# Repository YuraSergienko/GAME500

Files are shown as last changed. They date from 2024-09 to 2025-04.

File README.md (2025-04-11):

# GAME500

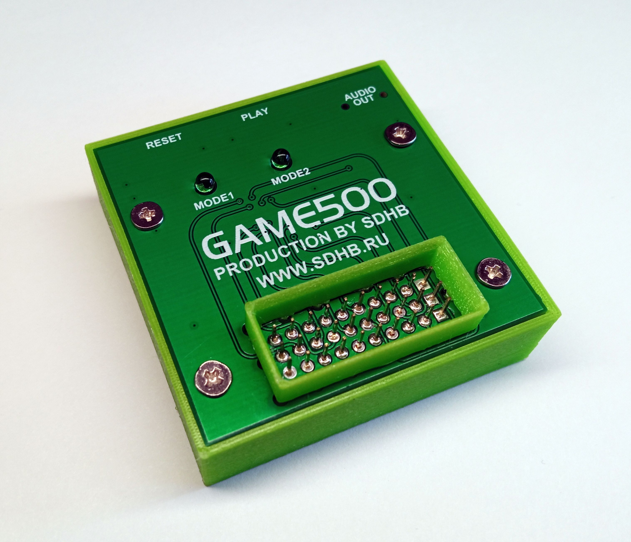
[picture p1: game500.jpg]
GAME500


<b>ROM картридж для компьютера "Вектор-06Ц"</b>

GAME500 - простое устройство для быстрой загрузки любимых программ. Для подключения к "Вектору" использется порт ПУ, а также при необходимости
магнитофонный вход. GAME500 эмулирует ROM картридж поддержка которого есть в большенстве загрузочных ПЗУ. Если же в "Векторе" установлено
заводское загрузочное ПЗУ без поддержки ROM картриджа, на GAME500 есть аудиовыход, который нужно подключить к магнитофонному входу "Вектора".
При нажатии кнопки "PLAY" на GAME500, с него воспроизводится небольшая программа-загрузчик с поддержкой ROM картриджей.

Содержание папок репозитория:<br>
asm - исходные коды для загрузчиков и файловой оболочки.<br>
box - stl модели корпусных деталей картриджа.<br>
doc - документация на изделие.<br>
flash - программа и файлы для подготовки bin файла для записи в микросхему флэш памяти W25Q128.<br>
gerber - GERBER файлы для производства печатной платы.<br>
src - проект в среде MounRiver для микроконтроллера CH32V103C8T6.<br>
src/obj/game500.hex - файл прошивки микроконтроллера CH32V103C8T6.<br>

<b>ROM cartridge for the Vector-06C computer</b>

GAME500 is a simple device for quickly loading your favorite programs. The "ПУ" port is used to connect to the "Vector", and if necessary,
the tape recorder input. GAME500 emulates a ROM cartridge, which is supported by most boot ROMs. If the "Vector" has a factory boot ROM
without support for a ROM cartridge, the GAME500 has an audio output that needs to be connected to the tape recorder input of the "Vector".
When you press the "PLAY" button on the GAME500, a small bootloader program with support for ROM cartridges is played from it.

Contents of repository folders:<br>
asm - source codes for loaders and file manager.<br>
box - stl models of cartridge body parts.<br>
doc - product documentation.<br>
flash - program and files for preparing a bin file for recording in the W25Q128 flash memory chip.<br>
gerber - GERBER files for PCB production.<br>
src - project in the MounRiver IDE for the CH32V103C8T6 microcontroller.<br>
src/obj/game500.hex - firmware file for the CH32V103C8T6 microcontroller.<br>

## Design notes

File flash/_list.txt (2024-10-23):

_game500.rom File manager
fdcosmos.rom ACongueteCosmos
afterwar.rom After The War
agress1.r0m Agressor
airfight.rom Air Fighter
AIDSJUN.ROM Aids! Jun
AIDSMID.ROM Aids! Mid
airforcs.rom Air Force
alfred.rom Alfred
alibaba.rom Alibaba&40Thiev
alambush.rom Alien Ambush
apdig.rom Ap-Digger
APEX.ROM Apex
arkanoid.rom Arkanoid
arkan4.rom Arkanoid mod
asteroids.rom Asteroids
assaut.rom Assaut
park.rom Athletic Land
bacbyl.rom Back
barman.rom Barman
Batle_Tank.rom Battle Tank
karate.rom BestOfTheBest
best.rom BestOfTheBest+
billy.rom Billy
binland.rom Binary Land
Binorum.rom Binorum
blackjack_cas.rom BlackJack
blaster.rom Blaster
bomber.rom Bomber
jungle_jps.rom Boogie Woogie J
BORDHOLL.ROM Border-Hollow
bouldush.rom Boulder Dash
boulderd.rom Boulder Dash2.0
bouldd11.rom Boulder Dash1.1
bouldd22.rom Boulder Dash2.2
house.rom Break House
BUSINESS.ROM Business
caeon.rom Caeon
cball.rom Cannon Ball
ceilon.rom Ceilon
chaser.rom Chaser
chasse.rom Chasse
chesse.rom Cheese
cheese2.rom Cheese2
SHAHM2.ROM Chess-2
chesmast2.rom Chess Master
CHESMAST.ROM Chessmaster
chipdale.rom Chip&Dale(alfa)
chronos.rom Chronos
colball.rom Color Ball
clrball_new.rom Color Ball New
collines.rom Color Lines
columns.rom Columns
columns2.rom Columns 2
columns3.rom Columns IBM
cookie.rom Cookie
cooky2.rom Cooky-2
cosman.rom Cosman
crapaut.rom Crapaut
crazy.rom Crazy Train
cronex.rom Cronex
CYBERMUT.ROM Cyber Mutant
cybernbr.rom Cybernoid
dangerick.rom Dangerous Rick
DATEAU.ROM Dateau
DFIGHT.ROM Death Fight
deathstr.rom Death Star
pyr-df99.rom DeathInPyramid
desolate.rom Desolate
dcountry.rom Diamond Country
dcountr2.rom DiamondCountry2
dino1.rom Dino
DIZZY-S.ROM Dizzy
donkong.rom Donkey Kong
DOWN.ROM Down To Earth
DEAR-BST.ROM DownToEarth BST
DEAR-RS.ROM DownToEarth RS
DEAR-RSY.ROM DownToEarth RSY
DOWN1.ROM Down To Earth
driller.rom Driller Tanks
airman.rom Duble Airman
dungeon.rom Dungeon
eaglesn.rom Eagle Snest
earth3.rom Earth Shaker
efa.rom Efa
ERASER.ROM Eraser
eric.rom Eric & Floaters
exolon.rom Exolon
ExolonM2.rom Exolon M2
fantom.rom Fantom
fantom2.rom Fantom2
FATAX.ROM Fatax
FATAXCOL.ROM Fatax Color
features.rom Features
filer.rom Filer
fire.rom Fire Rescue
flight.rom Flight
flyspirt.rom Flying Spirit
football.rom Footbal
forpostm.rom Forpost
fortuna.rom Fortuna
frogger.rom Frogger
fuite.rom Fuite
galaxan.rom Galaxan
ghostbus.rom Ghostbusters
global.rom Global Rally
hairwarr.rom Hair Warrior
harrier.rom Harrier
helicopt.rom Helicopter
indian.rom IndianNoBouken
intercep.rom Intercepter
karatet.rom Int. Karate T
jetset.rom Jet Set Willy
joeblade.rom Joe Blade
jumpjack.rom Jump-Jek
konfetti.rom Konfetti
LABIRINT.ROM Labirynt
LAND.ROM Land
landing.rom Landing
lapi.rom Lapi
liberator.rom Liberator
LODERUN.ROM Lode Runner
loderun2.rom Lode Runner2
LOGIC.ROM Logic
LIFE.ROM Life
macsit.rom Macsit
magpap1.r0m Magic Paper
mars.rom Mars
MAZE.ROM Maze
micmouse.rom Mickey Mous
NICKCHES.ROM Mikes Chess
mines.rom Mines
mineswep.rom Mine Sweeper
monstre.rom Monstre
moonbase.rom Moonbase
moonbugs.rom Moon Bugs
mower.rom Mower
TARZAN.ROM New Tarzan
niagar.rom Niagara Falls
ninja.rom Ninja Kage
ohmummy.rom Oh, Mummy
osciller.rom Osciller
outrun.rom Outrun
pacman.rom Pac-Man
PACMNCLR.ROM Pac-Man Color
pairs.rom Pairs
pdizzy.rom Panic Dizzy
PARITY.ROM Parity
pif-paf.rom Pif-Paf
pillars.rom Pillars
pipedr.rom Pipe Dream
pitongln.rom Piton GLN
polygame.rom Polygame
pool.rom Pool
preda1im.rom Predator 1
predato2.rom Predator 2
psst.rom Psst
pusher.rom Pusher
push.rom Push
putup.rom Putup
raider.rom Raider
RAIDER2.ROM Raider2
ranger.rom Ranger
REVSEX1.ROM Reverse Sex1
REVSEX2.ROM Reverse Sex2
REVERSI.ROM Reversi
riseout.rom Riseout
ROBBO1.ROM Robbo
ROBBO2.ROM Robbo-II
ROBBO3.ROM Robbo-III
robotek.rom Roboteka
rockman.rom Rock Man
rockman2.rom Rock Man2
rockman16.rom Rock Man16
rockford.rom Rockford
rotors.rom Rotors
runner.rom Runner
runer_ok.rom Runner OK
SABOTEUR.ROM Saboteour
salesman.rom Salesman
seggs.rom Scramble Eggs
sherly.rom Sherly
shoptour.rom Shop Tour
sidearm.rom Side Arm
snake.rom Snake
snake2.rom Snake2
sland.rom Snare Land
SOBDOG.ROM Sobdog
spcdemon.rom Space Demon
SPMEGAIM.ROM Space Megatron
spacop.rom Spacor
sdemise.rom Spy's Demise
stalker.rom Stalker
STARWARS.ROM Star Wars
starfighter.rom Starfighter
stars.rom Stars
stars2.rom Stars II
stepjump.rom Step And Jump
STINGER2.ROM Stinger 2
stonkers.rom Stonkers
iexpress.rom Stop Express
sgibbon.rom Super Gibbon
maric.rom Super Maric
superwea.rom Super Weapon
tankbat.rom Tank Battalion
tankwars.rom Tank Wars
terminus.rom Terminus
tetrisk.rom Tetris K
RUNERMAN.ROM The Ranner Man
tower.rom Tower
TRANSMUT.ROM Trans Muter
TRIP.ROM Trip
tron.rom Tron
TUTANKH2.ROM Tutankhamun
upriver.rom Up The River
w1.rom W-1
WAMPIRL.ROM Wampir Land
warp.rom Warp, Warp
westbank.rom West Bank
whouse.rom Wonder House
xorz.rom Xorz
xonix.rom Xonix
XONIXS.ROM Xonix S
xonixsn.rom Xonix SN
xonix_copy.rom Xonix OK
xyzolog.rom Xyzolog
zodiac.rom Zodiak
sokoban.rom Zoko-Ban
xzone.rom Zone X
ZORYT.ROM Zoryt
ochko101.rom 101 Очко
semvinej.rom 7 Виней
abrams.rom Абрамс
ADSKOK.ROM Адскок
akula.rom Акула
ambal.rom Амбал
ambalm.rom Амбал-М
arktika.rom Арктика
arktika_.rom Арктика2
armiya8.rom Армия 8
ATNINJA.ROM Атака Ниндзя
BILLIARD.ROM Биллиард
boldercr.rom Болдер
bolder2.rom Болдер 2
bolderm.rom Болдер-М
bolderpp.rom Болдер++
bombard.rom Бомбардировщик
BRONEVIK.ROM Броневик
burya.rom Буря в пустыне
vertolet.rom Вертолёт
vodolaz.rom Водолаз
vozdshar.rom Воздушный Шар
voleybol.rom Волейбол
vorishka.rom Воришка
gpatrul.rom Гала Патруль
gomoku.rom Го-Моку
golkiper.rom Голкипер
grotohod.rom Гротоход
dengolos.rom Деньголов
digger.rom Диггер
dizzi.rom Диззи
doroga.rom Дорога
irworld.rom Железный мир
LIFE2.ROM Жизнь
zamok.rom Замок
spacewar.rom Звездные Войны
sranger.rom Звездный Ренжер
ZPLANETA.ROM Зеленая Планета
ZONA.ROM Зона Будущего
CRITTERS.ROM Зубастики
istrebit.rom Истребитель
jeti.rom Йети
jeti2.rom Йети 2
karti.rom Карты
karateka.rom Каратека
karatek.rom Каратэ
kvadrati.rom Квадраты
kirash.rom Кираш
KIJANKA.ROM Киянка
KIJANKA2.ROM Киянка 2
KLAD.ROM Клад
klad2.rom Клад2
KLETKA.ROM Клетка
kobra.rom Кобра
KOLOBEG.ROM Колобег
KOLOPUNC.ROM Колобок
kolobiha.rom Колобиха
commandz.rom Коммандер
kotprigun.rom Кот-прыгун
kotribolov_copy.rom Кот-рыболов
kresnull.rom Крестики-Нолики
labir1.rom Лабиринт-1
lender.rom Лэндер
lendern.rom Лэндер-Н
MAGSHAR.ROM Магический Шар
mirsm.rom Мир Смерти
mohotnik.rom Морской Охотник
mohotni2.rom МорскойОхотник2
NARDI.ROM Нарды
nashchha.rom Нашествие
nupogodi.rom Ну, Погоди
ochko.rom Очко
ohota.rom Охота
parashut.rom Парашютисты
pasjansi.rom Пасьянсы
pakmanen.rom Пекманёнок
pecshera.rom Пещера
PESCHER1.ROM Пещера 2
pesprizr.rom Пещера Призраков
PITON.ROM Питон Успид
pitong.rom Питон
PLANETA.ROM Планета Птиц
plyuk.rom Плюк
poddavki.rom Поддавки
poker.rom Покер
polet.rom Полёт
popcorn.rom Попкорн
poprigun.rom Попрыгунчик
posad06c.rom Посадка
POHIWANA.ROM ПохожденияИвана
PREZID.ROM Президент
PRUZASOV.ROM ПрограммаУжасов
plifter.rom Пьяный Лифтёр
incurzion.rom Рива Рейд
SHASHKI.ROM Русские Шашки
rembo.rom Рэмбо
sabotaz.rom Саботаж
samuray.rom Самурай
spacesaf.rom СафариЗаВампирм
SEKA.ROM Сека
slalom.rom Слалом
sokoban_copy.rom Сокобан
sokzamka.rom Сокровища Замка
faraon.rom СокровищФараона
spichki.rom Спички
spsmerti.rom Спутник Смерти
spgroup1.rom Спецгруппа
sragen1.rom Сражение
sragen2.rom Сражение 2
srazsnlo.rom Сражение с НЛО
ot.rom Старая Башня
SUPKALAH.ROM Супер Калах
TANK.ROM Танк 
tennis_copy.rom Теннис
tetris.rom Тетрис
tetrisii.rom Тетрис II
tetriso.rom Тетрис-О
tetrisok.rom Тетрис-ОК
tetrisp.rom Тетрис-П
tir.rom Тир
trutni.rom Трутни
turboudav.rom Турбоудав
UGOLKI.ROM Уголки
uzas1.rom Ужас 1
uzas2.rom Ужас 2
UZAS3.ROM Ужас 3
flyer.rom Флаер
formula1.rom Формула 1
himiya.rom Химия
cvkvadr.rom Цветные квадрат
circus.rom Цирк
chsund1.rom Чудо Сундук1
chsund2.rom Чудо Сундук2
chsund3.rom Чудо Сундук3
sharik.rom Шарик
KLASSHES.ROM Шахматы
SHAHM1A.ROM Шахматы 1.1
SHAHM4.ROM Шахматы
shturm.rom Штурм
animator21.rom Аниматор
dekorator11.rom Декоратор
karandas.rom Карандаш
REMBRANT.ROM Рембранд
MICROGR.ROM Micrograf
coman.rom Гр.ред. Coman
masced.rom Гр.ред. Masc Ed
M_UZOR.ROM Редактор узоров
spraite.rom РедакторСпр-тов
spted.rom Sprite Editor
CHAR.ROM Ред.знакогенер.
ekran.rom Экран
organ1.rom Organ
mad.rom Mad MusicEditor
golos.rom Голос
horus.rom Horus
cmu.rom Цветомузыка
ColorOfMusic.rom Color of Music
cwmdelta.rom Цветомуз. Delta
lmusic1.rom LightMusic
lmusic2.rom LightMusic2
CVM1.ROM Цветомузыка CVM1
CVM2.ROM Цветомузыка CVM2
notebook.rom Записная Книжка
RETEX.ROM Retex Editor
TEXTAS.ROM Texstas
KTV.ROM Редактор текста
profy1.rom Тренажёр Профи 
bd.rom БД Эрис
sip.rom Система Поиска
elkubiki.rom Электр. Кубики
autocw.rom Auto CW
CW.ROM Терминалка
pdt-112.rom Психол. Тест
BIORITMY.ROM Биоритмы
bioritm.rom Биоритмы2
sexschol.rom Школа Секса
SEXOR.ROM Sexor
bas261.rom Basic 2.61
bas262.rom Basic 2.62
basicm.rom Basic M
baskor.rom Basic Корвет
basicsig.rom Basic ПО Сигнал
reklama.r0m BAS Реклама
INFOR-1.r0m BAS Inform 1     
INFOR-2.r0m BAS Inform 2    
t_ataka.r0m BAS Торп. атака
kalah.r0m BAS Калах
space_station.r0m BAS Space Stat.
corpse.r0m BAS Corpse
vitamino.r0m BAS Витамино     
forth-83.rom Forth-83
LSPAS-I.ROM ЛС-Паскаль инт.
LSPAS-K.ROM ЛС-Паскаль ком.
mon25c.rom Монитор 2.5
mon26.rom Монитор 2.6
mon28.rom Монитор 2.8
mon40.rom Монитор 4
smon35g.rom Супер Монитор3.5
smon40.rom Супер Монитор4
mon1200.rom Монитор 1200
monpribm.rom Монитор Pribor
monvz1.rom МониторВзломщик
MONHEDM.ROM Monitor High
rk86.rom Монитор РК-86
micro_rk.rom Микроша-РК86
testtp.rom Тест Техпрогона
testustr.rom Тест Устройств
brdtestx.rom Border Test
kdtest.rom Тест квазидиска
kdtest2.rom Тест квазидиск2
GRAYTEST.ROM Тест серого
ozu.rom Тест ОЗУ
ozuda0.rom Тест ОЗУ2
ozudtprl.rom Тест ОЗУ3
TESTAY.ROM Test AY
TESTELD.ROM Test RAM Дождь
testram.rom Test RAM
fastpalprog.rom Тест FastPalPrg
cpress3.rom Press3.3 copier
goody.rom КопировщикGoody
fttcopy.rom FTT Copy
copy-copy.rom Copy-Copy
turbo.rom Turbo Copy
archiv13.rom Архиватор
dilarh.rom Копир-Архватор
copypack.rom Копир-упаковщик
beverley.rom ВИ53 Демо
gtoc64.rom ДемоPhaser c64
object3d.rom Demo 3D Objects
rc38.rom 3D demo rc38
rc46.rom 3D demo rc46
chip.rom Chip
art.rom Демо Art
art1.rom Демо Art 1
art2.rom Демо Art 2
art3.rom Демо Art 3
art4.rom Демо Art 4
art5.rom Демо Art 5
art6.rom Демо Art 6
art7.rom Демо Art 7
ART2-01.rom Демо Art2 1
ART2-02.rom Демо Art2 2
ART2-03.rom Демо Art2 3
ART2-04.rom Демо Art2 4
ART2-05.rom Демо Art2 5
ART2-06.rom Демо Art2 6
ART2-07.rom Демо Art2 7
ART2-08.rom Демо Art2 8
ART2-09.rom Демо Art2 9
ART2-10.rom Демо Art2 10
bazis.rom Демо Базис
musworld.rom Демо Musworld
sabrina.rom Демо Sabrina
beatles.rom Демо Beatles
demon.rom Муз.демо Demon
fancy.rom Муз.демо Fancy
KRISTI.ROM Демо Kristi
amiga.rom Демо Amiga
accel2.rom Демо Accel2
f29.rom Демо F29
pgz.rom Демо ПГЗ
pmasha.rom Демо Maria
realdemo.rom Демо Realdemo
spiral.rom Демо Spiral
artsamar.rom Art Samara
lyra2-3.rom Демо Lyra2-3
message.rom MuzDemo
man.rom Демо Man
ollilisa.rom Демо Olli&Lissa
komar.rom Комар
byte2122.rom Байт 21, 22

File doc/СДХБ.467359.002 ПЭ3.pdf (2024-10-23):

Изм. Лист | № докум. | Подп. | Дата
| Разраб. | Сергиенко | | | GAME500 Перечень элементов | Лит. | Лист | Листов
Пров. | | | | A 1

Н.контр.
Утв.
www.sdhb.ru Инв. № подл. Подп. и дата Взам. инв. № Инв. № дубл. Подп. и дата Справ. № Перв. примен. СДХБ.467359.02 | Конденсаторы
C1-C4, GRM21BR71H104K | | 6
C7,C8
C5, C6 GRM2165C1H270JZ01D | | 2
C9 | GRM21BR61E106KA73L | 1
C10 | GRM2165C1H222JA01D | 1
C11 | GRM21BR71C105KA01K | 1
| Микросхемы
DA1 | LD1117AS33TR | 1
DD1 | CH32V103C8T6 | 1
DD2 | W25Q128JVSIQ | 1
| Резисторы
R1-R7, RC0805FR-0710KL | | 8
R11
R8, R9 RC0805FR-07510RL | | 2
R10 | RC0805FR-0724KL | 1
| Диоды
VD1, VD2 L-1154GT | | 2
| Разъемы
X1-X3 PLL1.27-20 | | 3
XS1 | PJ-W17-03 | 1
| Прочие элементы
SB1, SB2 Кнопка IT4-1102USA | | 2
ZQ1 | Кварц HC-49US, 8 МГц | 1
| | | СДХБ.467359.02 ПЭ3

Поз.
обозначение
Наименование | Кол. Примечание
Копировал | Формат A4

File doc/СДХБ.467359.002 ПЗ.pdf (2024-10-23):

Перв. примен. СДХБ.467359.002 Справ. № Подп. и дата Инв. № дубл. Взам. Инв. № Подп. и дата

| | | | СДХБ.467359.002 ПЗ
| Изм. Разраб. Лист | Сергиенко № докум. | Подп. | Дата Инв. № подл. | GAME500 Пояснительная записка | Лит. | Лист | Листов
Пров. | | | | А | | | 1 | 6
Н. контр. | www.sdhb.ru
Утв.
| Формат А4

## GAME500

## СДХБ.467359.002

## ПОЯСНИТЕЛЬНАЯ ЗАПИСКА

Подп. и дата Инв. № дубл. Взам. инв. № Подп. и дата Инв.№ подл. СДХБ.467359.002 ПЗ

Лист

Изм. | Лист | № докум. | Подп. | Дата

2

ВВЕДЕНИЕ

GAME500 - простое устройство для быстрой загрузки любимых программ. Для подключения к "Вектору" используется порт ПУ, а также при необходимости магнитофонный вход. GAME500 эмулирует ROM картридж поддержка которого есть в большинстве загрузочных ПЗУ. Если же в "Векторе" установлено заводское загрузочное ПЗУ без поддержки ROM картриджа, на GAME500 есть аудиовыход, который нужно подключить к магнитофонному разъему "Вектора". При нажатии кнопки "PLAY" на GAME500, с него воспроизводится небольшая программка-загрузчик с поддержкой ROM картриджей.

### 1. СБОРКА ПЕЧАТНОЙ ПЛАТЫ

### 1.1. СБОРКА РАЗЪЕМА

Так как разъемы СНП34-30В довольно дорого и сложно приобрести, в GAME500 используется его замена. Штырьки используются от PLS гребенки, а корпус печатается на 3D принтере.

Прежде чем начать сборку платы необходимо подготовить PLS гребенки. Для этого PLS гребенка с 20 контактами и с шагом 1.27 прореживается, через одну, чтобы получилась гребенка с 10 контактами и шагом 2.54. Далее гребенка вставляется в пустую печатную плату. Прижимая в плотную к плате пластиковой держатель штырьков добиваются максимальной длины контактов (Рис. 1).

Рисунок 1

Подп. и дата Инв. № дубл. Взам. инв. № Подп. и дата Инв.№ подл. СДХБ.467359.002 ПЗ

3

Необходимо изготовить три таких гребенки. После сборки платы они запаиваются в последнюю очередь, используя для выравнивания подходящий ответный разъем типа СНП34 или ПУ выход "Вектора". После запайки гребенок необходимо удалить пластиковые держатели и установить корпус-рамку разъема, которая фиксируется оплавлением с обратной стороны.

### 1.2. МОНТАЖ СВЕТОДИОДОВ

Светодиоды вставляются в соответствующие отверстия, контакты разгибаются и отрезаются так, чтобы они попадали на контактные площадки, после чего запаиваются.

При установке соблюдайте правильную полярность светодиодов.

### 1.3. МОНТАЖ КНОПОК

Перед монтажом кнопок необходимо отогнуть торчащий лепесток корпуса кнопки на 90 градусов (Рис. 2), после чего кнопка запаивается большим количеством припоя.

Рисунок 2

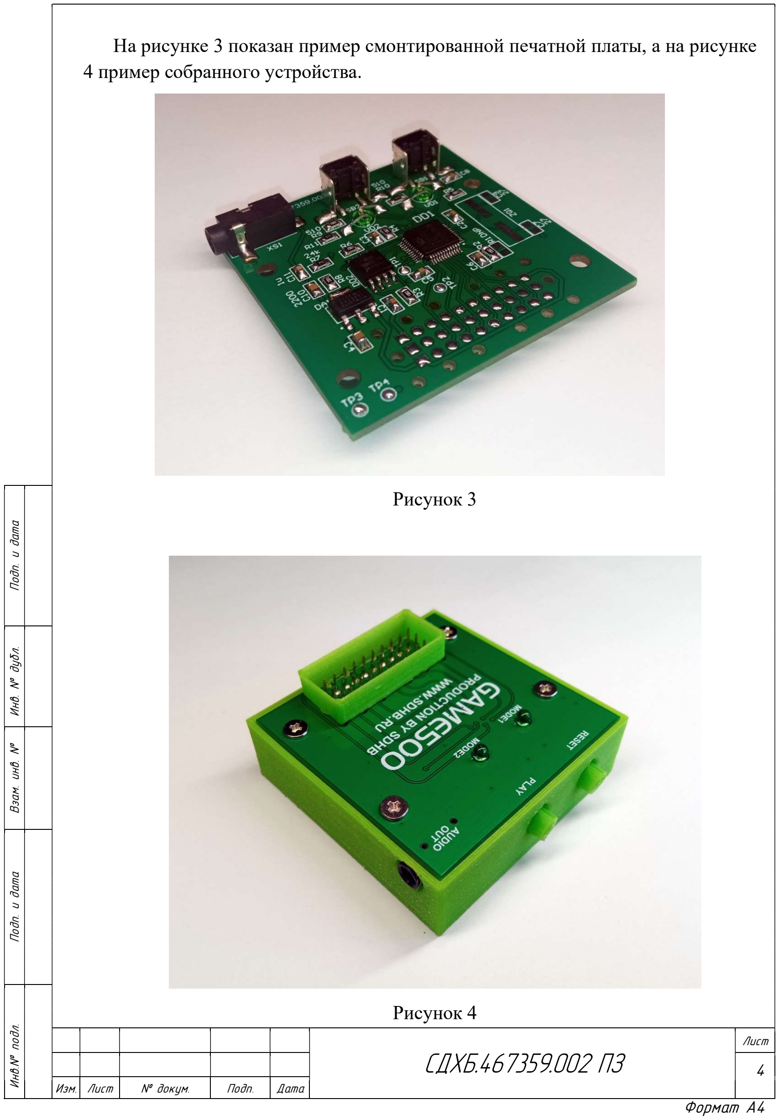
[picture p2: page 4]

Подп. и дата Инв. № дубл. Взам. инв. № Подп. и дата Инв.№ подл. СДХБ.467359.002 ПЗ

4

На рисунке 3 показан пример смонтированной печатной платы, а на рисунке 4 пример собранного устройства.

Рисунок 3

Рисунок 4

Подп. и дата Инв. № дубл. Взам. инв. № Подп. и дата Инв.№ подл. СДХБ.467359.002 ПЗ

5

### 1.4. МОНТАЖ И ПРОГРАММИРОВАНИЕ МИКРОСХЕМЫ W25Q128

Перед запайкой микросхемы W25Q128 в неё необходимо предварительно записать bin файл с «векторовскими» программами. Для этого можно использовать самодельные переходники или использовать готовые (Рис. 5).

Рисунок 5

### 1.5. МОНТАЖ И ПРОГРАММИРОВАНИЕ МИКРОКОНТРОЛЛЕРАМ

Микроконтроллер можно программировать на полностью запаянной плате. Для подключения программатора на плате есть четыре точки для пайки:

TP1 - DIO

TP2 - CLK

TP3 - 3V3

TP4 - GND

Для программирования используется программатор WCH-Link-RO-1v3 или WCHlink Mini CH549F. Файл прошивки называется game500.hex.

Подп. и дата Инв. № дубл. Взам. инв. № Подп. и дата Инв.№ подл. СДХБ.467359.002 ПЗ

6

### 2. СОЗДАНИЕ ФАЙЛА ДЛЯ ПРОШИВКИ W25Q128

Для создания bin файла, содержащего набор «векторовских» программ, используется программа _make_flash.py написанная на языке Phyton. Для запуска программы необходимо скачать Phyton с официального сайта и установить. В папке с программой должны находиться все «векторовские» программы, из которых необходимо сформировать bin файл. Также в папке должен находиться файл _game500.rom – это файловая оболочка необходимая для работы GAME500. Также в папке с программой должен находиться файл _list.txt в котором находится список «векторовских» программ, из которых необходимо сформировать bin файл. Каждая строка файла _list.txt должна содержать имя «векторовского» файла и через пробел его название, которое будет отображаться в файловой оболочке. Имя файла не должно содержать пробелы. Название может содержать пробелы, длина названия не более 15 символов. Каждая строка файла _list.txt должна заканчиваться ENTER (перевод строки).

В результате успешной работы программы появится файл _flash.bin, который необходимо записать в микросхему W25Q128.

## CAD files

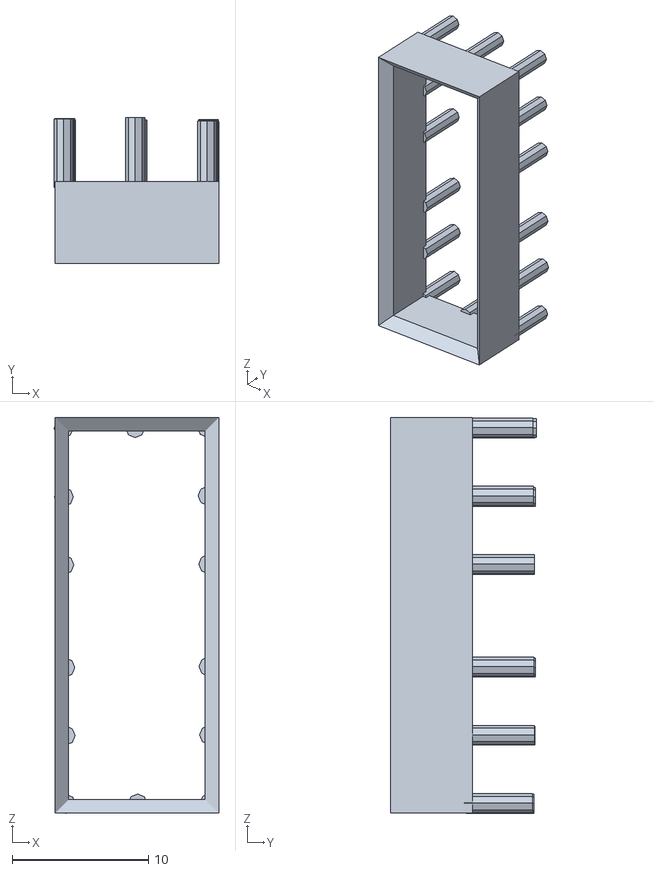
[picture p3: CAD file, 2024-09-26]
box/GAME500_socket.stl
12.1 x 10.7 x 29.0

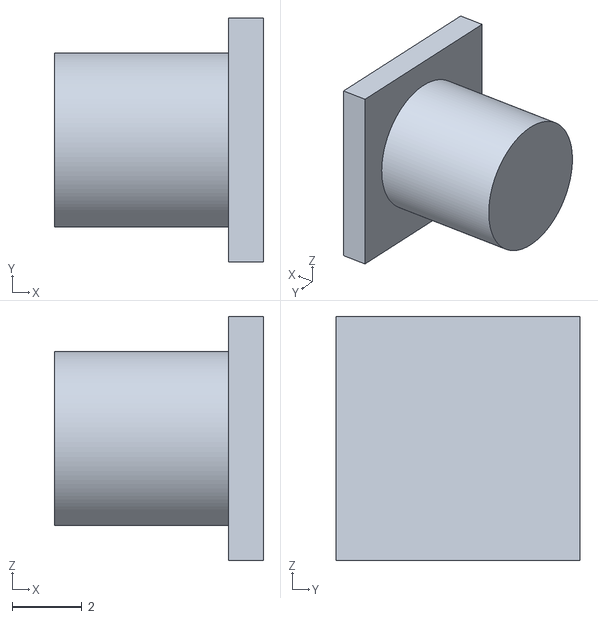
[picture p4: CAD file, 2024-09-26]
box/GAME500_button.stl
6.00 x 7.00 x 7.00

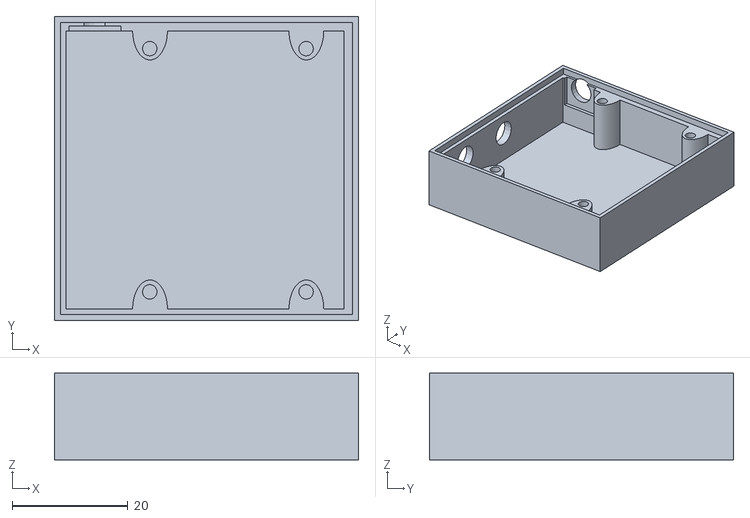
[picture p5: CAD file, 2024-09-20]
box/GAME500_box.stl
52.5 x 52.5 x 15.0

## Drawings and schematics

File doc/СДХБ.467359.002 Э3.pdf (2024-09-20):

# 5V PORT A 0x07

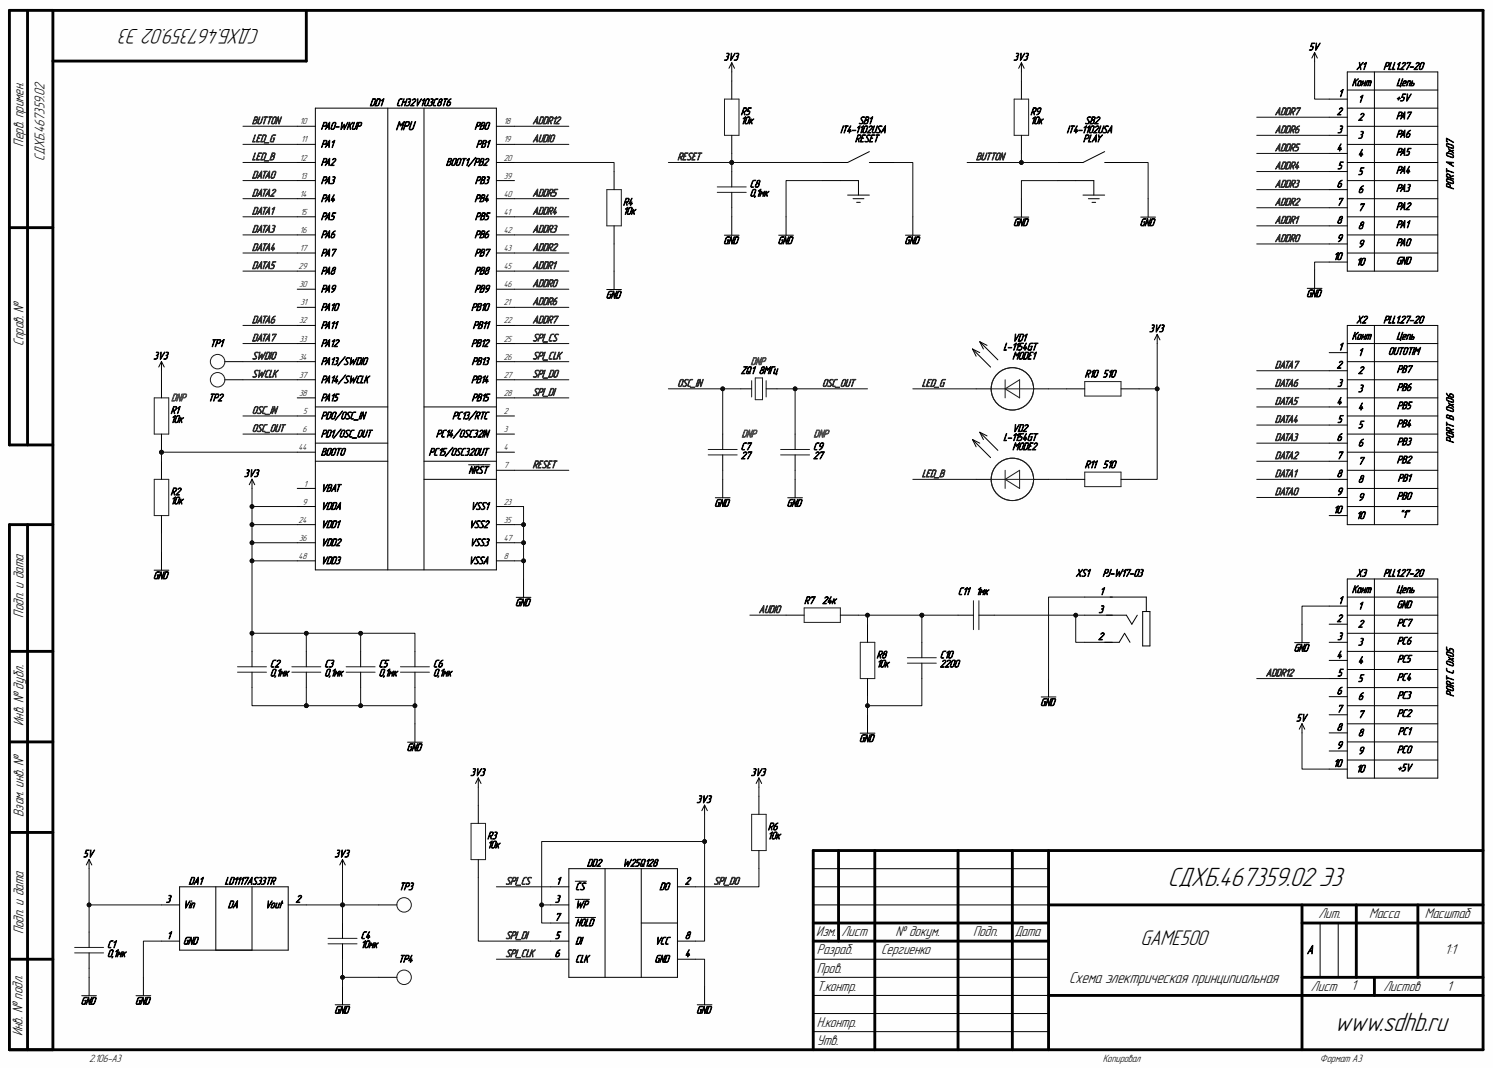
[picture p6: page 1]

Инв. № подл. Инв. № дубл. Подп. и дата Взам. инв. № Подп. и дата Перв. примен. Справ. №

Конт | Цепь
1 | +5V

3 | PA6
4 | PA5
5 | PA4
6 | PA3

3 | PB6
4 | PB5
5 | PB4
6 | PB3
7 | PB2
8 | PB1

1 | GND
2 | PC7
3 | PC6
4 | PC5
5 | PC4
6 | PC3
7 | PC2
8 | PC1
9 | PC0
10 | +5V

Разраб. | Сергиенко
Пров.
Т.контр. | | Лист 1 | Листов 1

Н.контр.
Утв.

www.sdhb.ru

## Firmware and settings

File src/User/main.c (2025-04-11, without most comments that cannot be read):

#include "debug.h"
#include "game500.h"
int main(void)
{

    my_rcc_init();
    Delay_Init();
    gpio_init();
    Delay_Ms(1);
    flash_init1();
    GPIO_SetBits(GPIOC, LED_R);
    GPIO_SetBits(GPIOA, LED_G);
    GPIO_SetBits(GPIOA, LED_B);

// ENTER MODE1
MODE1:
    MODE2_FLAG = 0;
    while(MODE2_FLAG != 2)
    {
        if(GPIO_ReadInputDataBit(GPIOA, PLAY) == Bit_RESET) play_loader();
        PU_addr=0;
        PU_addr_in = ((uint16_t)GPIOB->INDR);
        PU_addr |= (uint8_t)((PU_addr_in & ADDR0) >> 9);
        PU_addr |= (uint8_t)((PU_addr_in & ADDR1) >> 7);
        PU_addr |= (uint8_t)((PU_addr_in & ADDR2) >> 5);
        PU_addr |= (uint8_t)((PU_addr_in & ADDR3) >> 3);
        PU_addr |= (uint8_t)((PU_addr_in & ADDR4) >> 1);
        PU_addr |= (uint8_t)((PU_addr_in & ADDR5) << 1);
        PU_addr |= (uint8_t)((PU_addr_in & ADDR6) >> 4);
        PU_addr |= (uint8_t)((PU_addr_in & ADDR7) >> 4);
        if(PU_addr == 0xaa)
        {
            MODE2_FLAG = 1;
        }
        else if(PU_addr == 0x55)
        {
            if(MODE2_FLAG == 1)
            {
                MODE2_FLAG = 2;
            }
            else
            {
                MODE2_FLAG = 0;
            }
        }
        else
        {
            MODE2_FLAG = 0;
        }
        PU_data = ROM_menu[PU_addr];
        PU_data_out=0;
        PU_data_out |= ((PU_data & 0x01) << 3);
        PU_data_out |= ((PU_data & 0x02) << 4);
        PU_data_out |= ((PU_data & 0x04) << 2);
        PU_data_out |= ((PU_data & 0x08) << 3);
        PU_data_out |= ((PU_data & 0x10) << 3);
        PU_data_out |= ((PU_data & 0x20) << 3);
        PU_data_out |= ((PU_data & 0x40) << 5);
        PU_data_out |= ((PU_data & 0x80) << 5);
        PU_data_out |= LED_B;
        GPIOA->OUTDR = (uint32_t)PU_data_out;
    }
    GPIO_SetBits(GPIOC, LED_R);
    GPIO_SetBits(GPIOA, LED_G);
    GPIO_ResetBits(GPIOA, LED_B);

// MODE2
    MODE1_FLAG = 0;
    byte_addr = 0;
    while((((uint16_t)GPIOB->INDR) & ADDR12) == 0) // wait clock
    {
    }
    while((((uint16_t)GPIOB->INDR) & ADDR12) !=0 )
    {
    }
    PU_addr=0; // read H byte
    PU_addr_in = ((uint16_t)GPIOB->INDR);
    PU_addr |= (uint8_t)((PU_addr_in & ADDR0) >> 9);
    PU_addr |= (uint8_t)((PU_addr_in & ADDR1) >> 7);
    PU_addr |= (uint8_t)((PU_addr_in & ADDR2) >> 5);
    PU_addr |= (uint8_t)((PU_addr_in & ADDR3) >> 3);
    PU_addr |= (uint8_t)((PU_addr_in & ADDR4) >> 1);
    PU_addr |= (uint8_t)((PU_addr_in & ADDR5) << 1);
    PU_addr |= (uint8_t)((PU_addr_in & ADDR6) >> 4);
    PU_addr |= (uint8_t)((PU_addr_in & ADDR7) >> 4);
    file_addrH = PU_addr;
    while((((uint16_t)GPIOB->INDR) & ADDR12) == 0) // wait clock
    {
    }
    while((((uint16_t)GPIOB->INDR) & ADDR12) !=0 )
    {
    }
    PU_addr=0; // read L byte
    PU_addr_in = ((uint16_t)GPIOB->INDR);
    PU_addr |= (uint8_t)((PU_addr_in & ADDR0) >> 9);
    PU_addr |= (uint8_t)((PU_addr_in & ADDR1) >> 7);
    PU_addr |= (uint8_t)((PU_addr_in & ADDR2) >> 5);
    PU_addr |= (uint8_t)((PU_addr_in & ADDR3) >> 3);
    PU_addr |= (uint8_t)((PU_addr_in & ADDR4) >> 1);
    PU_addr |= (uint8_t)((PU_addr_in & ADDR5) << 1);
    PU_addr |= (uint8_t)((PU_addr_in & ADDR6) >> 4);
    PU_addr |= (uint8_t)((PU_addr_in & ADDR7) >> 4);
    file_addrL = PU_addr;
    file_addr = file_addrH * 0x100 + file_addrL;
    while(byte_addr != 0xe000)
    {
        while((((uint16_t)GPIOB->INDR) & ADDR12) == 0) // wait clock
        {
        }
        while((((uint16_t)GPIOB->INDR) & ADDR12) !=0 )
        {
        }
        PU_addr=0;
        PU_addr_in = ((uint16_t)GPIOB->INDR);
        PU_addr |= (uint8_t)((PU_addr_in & ADDR0) >> 9);
        PU_addr |= (uint8_t)((PU_addr_in & ADDR1) >> 7);
        PU_addr |= (uint8_t)((PU_addr_in & ADDR2) >> 5);
        PU_addr |= (uint8_t)((PU_addr_in & ADDR3) >> 3);
        PU_addr |= (uint8_t)((PU_addr_in & ADDR4) >> 1);
        PU_addr |= (uint8_t)((PU_addr_in & ADDR5) << 1);
        PU_addr |= (uint8_t)((PU_addr_in & ADDR6) >> 4);
        PU_addr |= (uint8_t)((PU_addr_in & ADDR7) >> 4);
        file_byte = read_flash(file_addr, byte_addr);
        write_PU2(file_byte);
        if(PU_addr == 0x81)
        {
            MODE1_FLAG = 1;
        }
        else if((PU_addr == 0x66) && (MODE1_FLAG == 1))
        {
            MODE1_FLAG = 2;
        }
        else
        {
            MODE1_FLAG = 0;
        }
        byte_addr = byte_addr+1;
        if(MODE1_FLAG == 2)
        {
            GPIO_ResetBits(GPIOA, LED_G);
            GPIO_SetBits(GPIOA, LED_B);
            goto MODE1;
        }
    }
    while(1) // what's going wrong
    {
        GPIO_ResetBits(GPIOC, LED_R);
        GPIO_SetBits(GPIOA, LED_G);
        GPIO_SetBits(GPIOA, LED_B);
    }

}

//--------------------------------------------------------------------------- subroutines
void play_byte(uint8_t byte)
{
    uint8_t x;
    for(x=0; x<8; x++)
    {
        if((byte & 0x80) == 0)
        {
            GPIO_SetBits(GPIOB, AUDIO);
            Delay_Us(NW);
            GPIO_ResetBits(GPIOB, AUDIO);
            Delay_Us(NW);
        }
        else
        {
            GPIO_ResetBits(GPIOB, AUDIO);
            Delay_Us(NW);
            GPIO_SetBits(GPIOB, AUDIO);
            Delay_Us(NW);
        }
        byte = byte << 1;
    }
}

//----------------------------------------------------------------------
void play_loader(void)
{
    GPIO_SetBits(GPIOA, LED_G);
    GPIO_ResetBits(GPIOA, LED_B);
    uint8_t send_byte;
    uint16_t b;
    for(b=0;b<580;b++)
    {
        send_byte = loader1[b];
        play_byte(send_byte);
    }
    GPIO_SetBits(GPIOA, LED_G);
    GPIO_ResetBits(GPIOA, LED_B);
}

//----------------------------------------------------------------------
void flash_init1(void)
{
    int i;
    uint8_t tx_data8;
    GPIO_ResetBits(GPIOB, SPI_DI);
    GPIO_ResetBits(GPIOB, SPI_CLK);
    GPIO_SetBits(GPIOB, SPI_CS);
    Delay_Ms(1);
// send ENABLE RESET command
        i=8;
        tx_data8=0x66;
        GPIO_ResetBits(GPIOB, SPI_CS);
        while(i!=0)
        {
            if((tx_data8 & 0x80) != 0)
            {
                GPIO_SetBits(GPIOB, SPI_DI);
            }
            else
            {
                GPIO_ResetBits(GPIOB, SPI_DI);
            }
            tx_data8 = tx_data8 << 1;
            i=i-1;
            GPIO_SetBits(GPIOB, SPI_CLK);
            GPIO_ResetBits(GPIOB, SPI_CLK);
        }
        i=0;
        while(i<5)
        {
            i=i+1;
        }
        GPIO_SetBits(GPIOB, SPI_CS);
// send RESET command
        i=8;
        tx_data8=0x99;
        GPIO_ResetBits(GPIOB, SPI_CS);
        while(i!=0)
        {
            if((tx_data8 & 0x80) != 0)
            {
                GPIO_SetBits(GPIOB, SPI_DI);
            }
            else
            {
                GPIO_ResetBits(GPIOB, SPI_DI);
            }
            tx_data8 = tx_data8 << 1;
            i=i-1;
            GPIO_SetBits(GPIOB, SPI_CLK);
            GPIO_ResetBits(GPIOB, SPI_CLK);
        }
        GPIO_SetBits(GPIOB, SPI_CS);
        GPIO_ResetBits(GPIOB, SPI_DI);
        GPIO_ResetBits(GPIOB, SPI_CLK);
        Delay_Ms(2);
}

//------------------------------- read byte from flash
uint8_t read_flash(uint16_t f_addr, uint16_t b_addr)
{
    int i;
    uint8_t tx_data8;
    uint32_t tx_data32=0;
    uint8_t rx_data;
    tx_data32 = 0x2000 * f_addr; // calculate flash address
    tx_data32 = tx_data32 + (uint32_t)b_addr; // calculate flash address
    GPIO_ResetBits(GPIOB, SPI_CS);
// send CMD
    i=8;
    tx_data8=0x03; // 0x03 - command to read 1 byte from flash
    while(i!=0)
    {
        if((tx_data8 & 0x80) != 0)
        {
            GPIO_SetBits(GPIOB, SPI_DI);
        }
        else
        {
            GPIO_ResetBits(GPIOB, SPI_DI);
        }
        tx_data8 = tx_data8 << 1;
        i=i-1;
        GPIO_SetBits(GPIOB, SPI_CLK);
        GPIO_ResetBits(GPIOB, SPI_CLK);
    }
// send ADDR
    i=24;
    tx_data32=tx_data32<<8;
    while(i!=0)
    {
        if((tx_data32 & 0x80000000) != 0)
        {
            GPIO_SetBits(GPIOB, SPI_DI);
        }
        else
        {
            GPIO_ResetBits(GPIOB, SPI_DI);
        }
        tx_data32 = tx_data32 << 1;
        i=i-1;
        GPIO_SetBits(GPIOB, SPI_CLK);
        GPIO_ResetBits(GPIOB, SPI_CLK);

    }
// read DATA
    i=8;
    rx_data=0;
    while(i!=0)
    {
        rx_data = rx_data << 1;
        if(GPIO_ReadInputDataBit(GPIOB, SPI_DO) != Bit_RESET)
        {
            rx_data = rx_data | 0x01;
        }
        i=i-1;
        GPIO_SetBits(GPIOB, SPI_CLK);
        GPIO_ResetBits(GPIOB, SPI_CLK);
    }
    GPIO_SetBits(GPIOB, SPI_CS);
    return rx_data;
}

//----------------------------------------------------------------------
void write_PU2(uint8_t write_data)
{
    uint16_t PU_data_out=0;
    PU_data_out |= ((write_data & 0x01) << 3);
    PU_data_out |= ((write_data & 0x02) << 4);
    PU_data_out |= ((write_data & 0x04) << 2);
    PU_data_out |= ((write_data & 0x08) << 3);
    PU_data_out |= ((write_data & 0x10) << 3);
    PU_data_out |= ((write_data & 0x20) << 3);
    PU_data_out |= ((write_data & 0x40) << 5);
    PU_data_out |= ((write_data & 0x80) << 5);
    PU_data_out |= LED_G;

    GPIOA->OUTDR = (uint32_t)PU_data_out;
    return;
}

//----------------------------------------------------------------------
void gpio_init(void)
{
    RCC_APB2PeriphClockCmd(RCC_APB2Periph_GPIOA, ENABLE);
    RCC_APB2PeriphClockCmd(RCC_APB2Periph_GPIOB, ENABLE);
    RCC_APB2PeriphClockCmd(RCC_APB2Periph_GPIOC, ENABLE);

    GPIO_InitTypeDef GPIO_InitStructure = {0};

    GPIO_InitStructure.GPIO_Pin = LED_R;
    GPIO_InitStructure.GPIO_Mode = GPIO_Mode_Out_PP;
    GPIO_InitStructure.GPIO_Speed = GPIO_Speed_50MHz;
    GPIO_Init(GPIOC, &GPIO_InitStructure);

    GPIO_InitStructure.GPIO_Pin = LED_G;
    GPIO_InitStructure.GPIO_Mode = GPIO_Mode_Out_PP;
    GPIO_InitStructure.GPIO_Speed = GPIO_Speed_50MHz;
    GPIO_Init(GPIOA, &GPIO_InitStructure);

    GPIO_InitStructure.GPIO_Pin = LED_B;
    GPIO_InitStructure.GPIO_Mode = GPIO_Mode_Out_PP;
    GPIO_InitStructure.GPIO_Speed = GPIO_Speed_50MHz;
    GPIO_Init(GPIOA, &GPIO_InitStructure);

    GPIO_InitStructure.GPIO_Pin = DATA0;
    GPIO_InitStructure.GPIO_Mode = GPIO_Mode_Out_PP;
    GPIO_InitStructure.GPIO_Speed = GPIO_Speed_50MHz;
    GPIO_Init(GPIOA, &GPIO_InitStructure);

    GPIO_InitStructure.GPIO_Pin = DATA1;
    GPIO_InitStructure.GPIO_Mode = GPIO_Mode_Out_PP;
    GPIO_InitStructure.GPIO_Speed = GPIO_Speed_50MHz;
    GPIO_Init(GPIOA, &GPIO_InitStructure);

    GPIO_InitStructure.GPIO_Pin = DATA2;
    GPIO_InitStructure.GPIO_Mode = GPIO_Mode_Out_PP;
    GPIO_InitStructure.GPIO_Speed = GPIO_Speed_50MHz;
    GPIO_Init(GPIOA, &GPIO_InitStructure);

    GPIO_InitStructure.GPIO_Pin = DATA3;
    GPIO_InitStructure.GPIO_Mode = GPIO_Mode_Out_PP;
    GPIO_InitStructure.GPIO_Speed = GPIO_Speed_50MHz;
    GPIO_Init(GPIOA, &GPIO_InitStructure);

    GPIO_InitStructure.GPIO_Pin = DATA4;
    GPIO_InitStructure.GPIO_Mode = GPIO_Mode_Out_PP;
    GPIO_InitStructure.GPIO_Speed = GPIO_Speed_50MHz;
    GPIO_Init(GPIOA, &GPIO_InitStructure);

    GPIO_InitStructure.GPIO_Pin = DATA5;
    GPIO_InitStructure.GPIO_Mode = GPIO_Mode_Out_PP;
    GPIO_InitStructure.GPIO_Speed = GPIO_Speed_50MHz;
    GPIO_Init(GPIOA, &GPIO_InitStructure);

    GPIO_InitStructure.GPIO_Pin = DATA6;
    GPIO_InitStructure.GPIO_Mode = GPIO_Mode_Out_PP;
    GPIO_InitStructure.GPIO_Speed = GPIO_Speed_50MHz;
    GPIO_Init(GPIOA, &GPIO_InitStructure);

    GPIO_InitStructure.GPIO_Pin = DATA7;
    GPIO_InitStructure.GPIO_Mode = GPIO_Mode_Out_PP;
    GPIO_InitStructure.GPIO_Speed = GPIO_Speed_50MHz;
    GPIO_Init(GPIOA, &GPIO_InitStructure);

    GPIO_InitStructure.GPIO_Pin = ADDR0;
    GPIO_InitStructure.GPIO_Mode = GPIO_Mode_IPD;
    GPIO_InitStructure.GPIO_Speed = GPIO_Speed_50MHz;
    GPIO_Init(GPIOB, &GPIO_InitStructure);

    GPIO_InitStructure.GPIO_Pin = ADDR1;
    GPIO_InitStructure.GPIO_Mode = GPIO_Mode_IPD;
    GPIO_InitStructure.GPIO_Speed = GPIO_Speed_50MHz;
    GPIO_Init(GPIOB, &GPIO_InitStructure);

    GPIO_InitStructure.GPIO_Pin = ADDR2;
    GPIO_InitStructure.GPIO_Mode = GPIO_Mode_IPD;
    GPIO_InitStructure.GPIO_Speed = GPIO_Speed_50MHz;
    GPIO_Init(GPIOB, &GPIO_InitStructure);

    GPIO_InitStructure.GPIO_Pin = ADDR3;
    GPIO_InitStructure.GPIO_Mode = GPIO_Mode_IPD;
    GPIO_InitStructure.GPIO_Speed = GPIO_Speed_50MHz;
    GPIO_Init(GPIOB, &GPIO_InitStructure);

    GPIO_InitStructure.GPIO_Pin = ADDR4;
    GPIO_InitStructure.GPIO_Mode = GPIO_Mode_IPD;
    GPIO_InitStructure.GPIO_Speed = GPIO_Speed_50MHz;
    GPIO_Init(GPIOB, &GPIO_InitStructure);

    GPIO_InitStructure.GPIO_Pin = ADDR5;
    GPIO_InitStructure.GPIO_Mode = GPIO_Mode_IPD;
    GPIO_InitStructure.GPIO_Speed = GPIO_Speed_50MHz;
    GPIO_Init(GPIOB, &GPIO_InitStructure);

    GPIO_InitStructure.GPIO_Pin = ADDR6;
    GPIO_InitStructure.GPIO_Mode = GPIO_Mode_IPD;
    GPIO_InitStructure.GPIO_Speed = GPIO_Speed_50MHz;
    GPIO_Init(GPIOB, &GPIO_InitStructure);

    GPIO_InitStructure.GPIO_Pin = ADDR7;
    GPIO_InitStructure.GPIO_Mode = GPIO_Mode_IPD;
    GPIO_InitStructure.GPIO_Speed = GPIO_Speed_50MHz;
    GPIO_Init(GPIOB, &GPIO_InitStructure);

    GPIO_InitStructure.GPIO_Pin = ADDR12;
    GPIO_InitStructure.GPIO_Mode = GPIO_Mode_IPD;
    GPIO_InitStructure.GPIO_Speed = GPIO_Speed_50MHz;
    GPIO_Init(GPIOB, &GPIO_InitStructure);

    GPIO_InitStructure.GPIO_Pin = SPI_CS;
    GPIO_InitStructure.GPIO_Mode = GPIO_Mode_Out_PP;
    GPIO_InitStructure.GPIO_Speed = GPIO_Speed_50MHz;
    GPIO_Init(GPIOB, &GPIO_InitStructure);

    GPIO_InitStructure.GPIO_Pin = SPI_CLK;
    GPIO_InitStructure.GPIO_Mode = GPIO_Mode_Out_PP;
    GPIO_InitStructure.GPIO_Speed = GPIO_Speed_50MHz;
    GPIO_Init(GPIOB, &GPIO_InitStructure);

    GPIO_InitStructure.GPIO_Pin = SPI_DI;
    GPIO_InitStructure.GPIO_Mode = GPIO_Mode_Out_PP;
    GPIO_InitStructure.GPIO_Speed = GPIO_Speed_50MHz;
    GPIO_Init(GPIOB, &GPIO_InitStructure);

    GPIO_InitStructure.GPIO_Pin = SPI_DO;
    GPIO_InitStructure.GPIO_Mode = GPIO_Mode_IN_FLOATING;
    GPIO_InitStructure.GPIO_Speed = GPIO_Speed_50MHz;
    GPIO_Init(GPIOB, &GPIO_InitStructure);

    GPIO_InitStructure.GPIO_Pin = AUDIO;
    GPIO_InitStructure.GPIO_Mode = GPIO_Mode_Out_PP;
    GPIO_InitStructure.GPIO_Speed = GPIO_Speed_50MHz;
    GPIO_Init(GPIOB, &GPIO_InitStructure);

    GPIO_InitStructure.GPIO_Pin = PLAY;
    GPIO_InitStructure.GPIO_Mode = GPIO_Mode_IN_FLOATING;
    GPIO_InitStructure.GPIO_Speed = GPIO_Speed_50MHz;
    GPIO_Init(GPIOA, &GPIO_InitStructure);
}

//----------------------------------------------------------------------
void my_rcc_init(void)
{
    RCC_SYSCLKConfig(RCC_SYSCLKSource_HSI);                 // switch system clock to HSI
    RCC_PLLCmd(DISABLE);                                    // disable PLL
    RCC_HSICmd(ENABLE);                                     // turn on HSI
    Delay_Us(10);                                           // delay for stability
    RCC_PLLConfig(RCC_PLLSource_HSI_Div2, RCC_PLLMul_12);    // set HSI/2 as PLL source, PLL multiplication factor = 12
    RCC_PLLCmd(ENABLE);                                     // turn on PLL
    Delay_Us(10);                                           // delay for stability
    while(RCC_GetFlagStatus(RCC_FLAG_PLLRDY) == RESET){};   // wait for PLL ready
    RCC_SYSCLKConfig(RCC_SYSCLKSource_PLLCLK);              // set PLL as SYSCLK source
}

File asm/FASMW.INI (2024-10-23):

[Environment]
Include=D:\Atolic_workspace\River_Raid\fasmw\INCLUDE
[Compiler]
Memory=65536
Priority=0
[Options]
SecureSelection=0
AutoBrackets=0
AutoIndent=1
SmartTabs=1
OptimalFill=0
ReviveDeadKeys=0
ConsoleCaret=1
TimeScroll=0
[Colors]
Text=0,0,0
Background=255,255,255
SelectionText=255,255,255
SelectionBackground=0,120,215
Symbols=48,48,240
Numbers=0,144,0
Strings=176,0,0
Comments=128,128,128
[Font]
Face=Courier New
Height=16
Width=0
Weight=0
Italic=0
CharSet=1
[Window]
Top=64
Left=96
Right=480
Bottom=388
Maximized=0
[Help]
Path=

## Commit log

2024-09-16 обновление файлов
2024-10-23 Update СДХБ.467359.002 ПЗ.pdf
2024-10-23 Update СДХБ.467359.002 ПЭ3.pdf
